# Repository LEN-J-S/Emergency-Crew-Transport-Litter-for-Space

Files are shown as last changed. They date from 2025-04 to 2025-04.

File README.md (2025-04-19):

# Emergency-Crew-Transport-Litter-for-Space
**NASA JSC HACKATHON 2024 - Winner Challenge Category**

Judged by: 
- Robert Howard - NASA
- Tracie Prater - NASA
- Martin Garcia - NASA
- Carson Hula - NASA

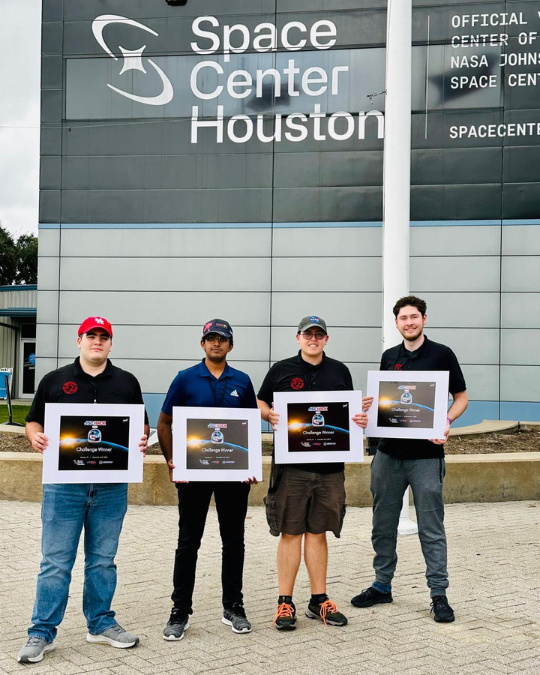
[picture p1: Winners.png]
Winning Photo


***Devpost Link: https://tinyurl.com/p4y2bk32***

## Inspiration

Being part of Robotics-UH and the different CAD challenges we have done in the past, this challenge was a benchmark for involving all engineering majors to brainstorm ideas for this challenge. The CAD assignment was the most exciting part the team was excited to have taken part in bringing different ideas while building the mechanism in CAD.

## What it does

The litter will be used for moving an incapacitated astronauts from their particular location to safety. The whole Litter will be 50lbs and 25lbs will be distributed with each astronauts to be carried at every location. The Litter will also be motor and self propelled. The Litter is also capable of moving for 14 Km at 4Km/hr.

## How we built it

We built the Litter first drawing it on paper and then analyzing all the criteria's are met, we proceeded to work the design on SolidWorks to get the sketch of the final prototype.

## Challenges we ran into

The main challenges we ran into is weight limit criteria of 50lbs for the overall system and locking the astronauts in a rigid position on the Litter. Another challenge we ran into was the design process as we had to go through 7 different design iterations.

## Accomplishments that we're proud of

We are proud that we have learned the different ideas brainstormed for the different iterations of design. We were also proud that different engineering teams brainstormed in each integral part of the design process. We are also proud that the we were able to manage tasks diligently and efficiently.

## What we learned

We learned how to solve different engineering challenges involved in designing the Litter. The different challenges allowed us to through different variations of the challenge to make the design better and meet the criteria of 50 lbs.

## What's next for Lunar Incapacitated Crew Rescue Litter

The next objective of the Litter is to be tested using different simulations in virtual environments and then to be tested in real-life environments. After the successful launches of these, they can be used in an emergency situation when an astronauts life is in danger.

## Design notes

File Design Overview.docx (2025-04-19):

Challenge 2: Emergency Crew Transport

Len Johns Shaji,Tyler Martelon, Aaron Hinkle, Ethan Bush, Celine Cherian

Overview of Design Criteria

Design and modeling of an emergency transportation system for an incapacitated crew member during an EVA. This system should be able to propel itself at a constant speed of 4 km/h and only require directional input from an operator. This system should hold onto an incapacitated astronaut and completely immobilize them during transport. The system should weigh no more than 50 lbs. (under earth gravity conditions) and be able to be broken down into pieces of at most 25 lbs. each for transport, additionally it must support up to 243 lbs. of added mass on the system. The system should take advantage of the construction of the xEMU space suit’s design where possible for the transport and immobilization of a crew member. Under the most ideal situation the system overall will not exceed 25 lbs. total to enable an entire system to be carried by a single individual however this is a highly encouraged design goal and not a design requirement.

Structural Design

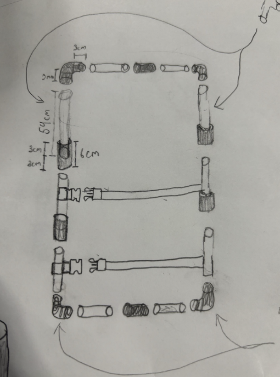
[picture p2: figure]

We based the system on a set of tubes fastened with clip-together fasteners. These tubes and fasteners are intended to be stored bundled together and connected to a crew member’s utility belt or thigh. A steel pin in each pipe section secures the pipes within their fasteners and provides a snug fit that partially retains the pipes due to friction. When fully assembled, this makes a roughly 182x70cm rectangular structure on which to secure a crew member.

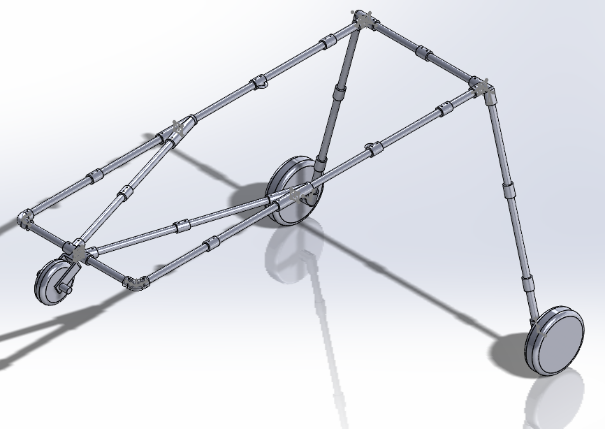
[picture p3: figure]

Securing a crew member to the pipe frame is accomplished by utilizing Beta cloth straps which secure entirely around the PLSS, CHUT, and arms on the upper body, over the knees, and under the thighs and ankles of the crew member. Additionally, there is hardware to mount the hardware pins located on the waist of the xEUV suit to the frame to further secure an individual to the system.

An early design concept for system frame

Once a crew member is secured to the frame the operator of the system can then fold out the two passive support wheels and one hub motor-powered propulsion wheel. Folding the wheels out is assisted by areas to insert the removable handlebar to add leverage and more easily get the system onto its wheels, once folded into the correct position these wheels and the sections of pipe they’re connected to will lock into place with a spring-loaded pin.

CAD model of full frame structure minus straps

Material Selection

As weight and strength are both important factors in this design, the material selection was a quite contentious subject in the design discussion. The biggest need of the design was for a structural material that could:

-Withstand the forces of weight added to the system

-Withstand the lunar environment and its hazards including regolith and solar radiation

-Be lightweight and enable the lightest possible system without sacrificing usability/stability.

With these parameters in mind, we quickly went through multiple options including PEEK plastic, fiberglass, Nomex netting, and others. We narrowed down our search to aluminum and carbon fiber and ended up switching between the two options for some time during the design process, eventually deciding on carbon fiber for the overall structure and aluminum for the fasteners.

Carbon fiber was selected for its excellent strength-to-weight ratio. Being an overall lightweight material with great tensile strength it was a good pick for the overall structure of the frame. While we considered making the fasteners out of carbon fiber as well, we ended up deciding that the forces being exerted on these pieces would probably be too high for it to be practical.

While aluminum was considered for the overall structure it was still too heavy despite its low mass compared to other metals. Rather after opting not to use carbon fiber fasteners a well we decided that using aluminum for the fasteners would be better to handle the forces acting on the fastener pieces.

Other than the structural components the straps were also a major material decision. Given the fact most fabrics aren’t well equipped for the conditions on the moon, we asked advice from some professionals in the space and were suggested to use either beta cloth or nomex fabric. Nomex was a promising prospect but was too heavy and contributed too much to the overall mass for us to consider going forward with. As the only other option was beta cloth and it had acceptable weight we selected it as the strap material.

Electronics integration

To enable the system to best be able to propel itself with the lowest weight possible we had to carefully consider the type of electronics that would be utilized. To maintain a speed of 4 km/h on the lunar surface we found we’d need to use a 70-watt motor running off of 24-volt power. In order to supply this motor with energy we opted to utilize a 13000 mAh lithium polymer battery for its power-to-weight ratio which allows a much greater energy density with less mass added to the system. The motor itself is a fully enclosed dust-proof hub motor integrated into the wheel assembly.

In order to control the motion of the system we’re utilizing wireless communication between two ESP32 microcontrollers and a three-position switch. The system has a simple selection between forward, backward, and stopped for motion as it is all it will need, any type of speed adjustment will add points of failure and mass that are not needed for the system’s function.

Computer-Aided Design work

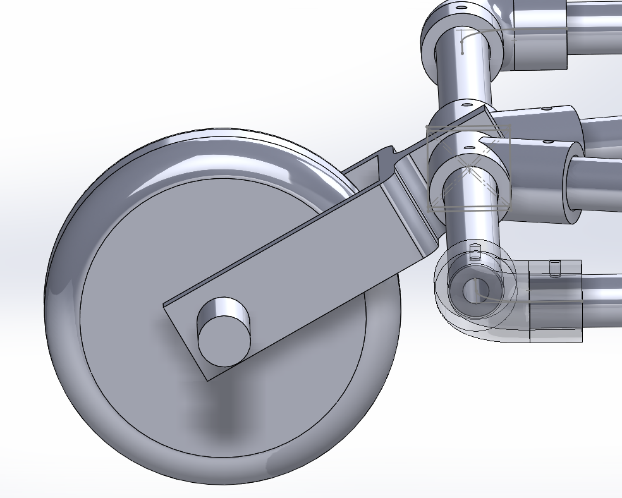
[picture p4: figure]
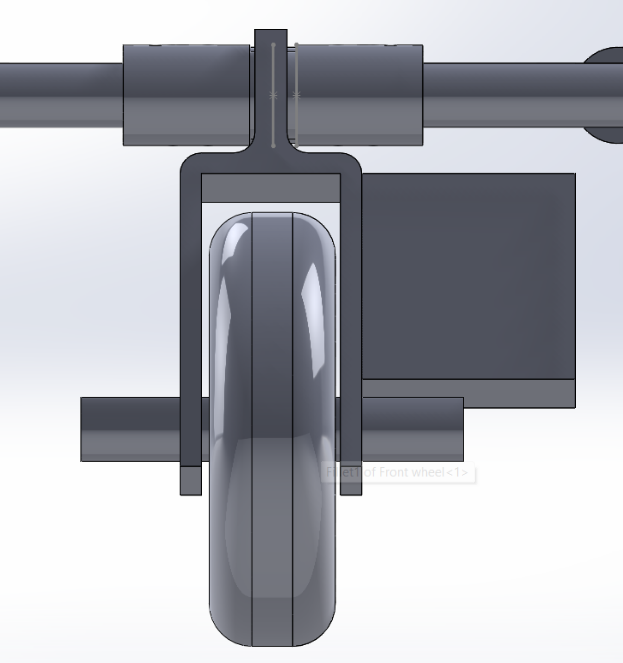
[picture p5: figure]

As part of this project, we made use of SolidWorks, a CAD software popular among mechanical engineering students at our university. We developed models for each part of the structure and combined them into a full assembly model. The following are images of the model produced.

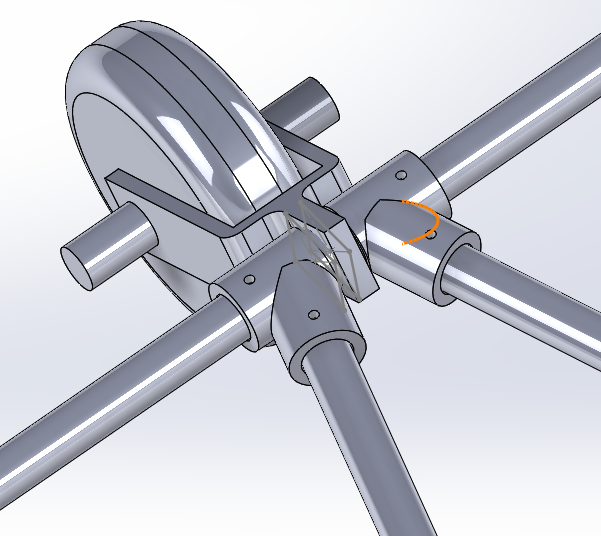
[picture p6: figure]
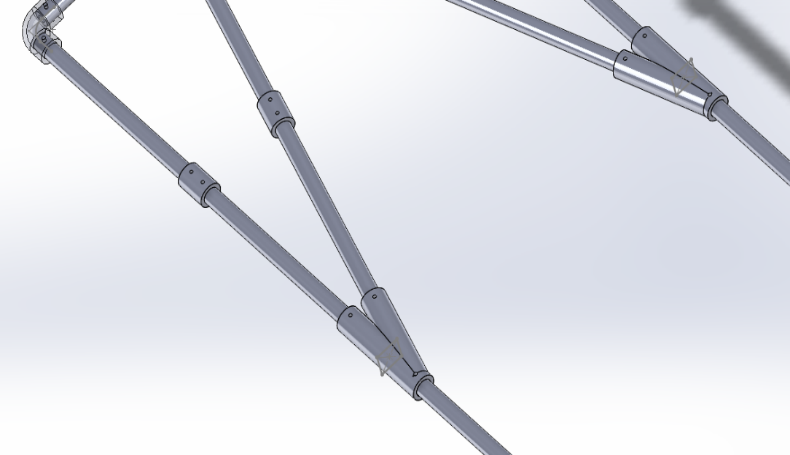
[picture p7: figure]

Cost Analysis

Below is the compiled cost data for all system components.

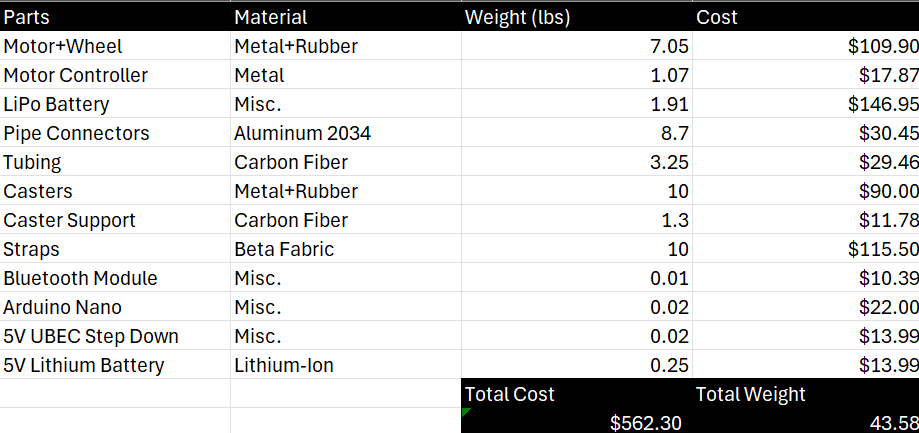
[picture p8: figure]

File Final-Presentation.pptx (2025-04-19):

## Challenge 2: Emergency Crew Transport

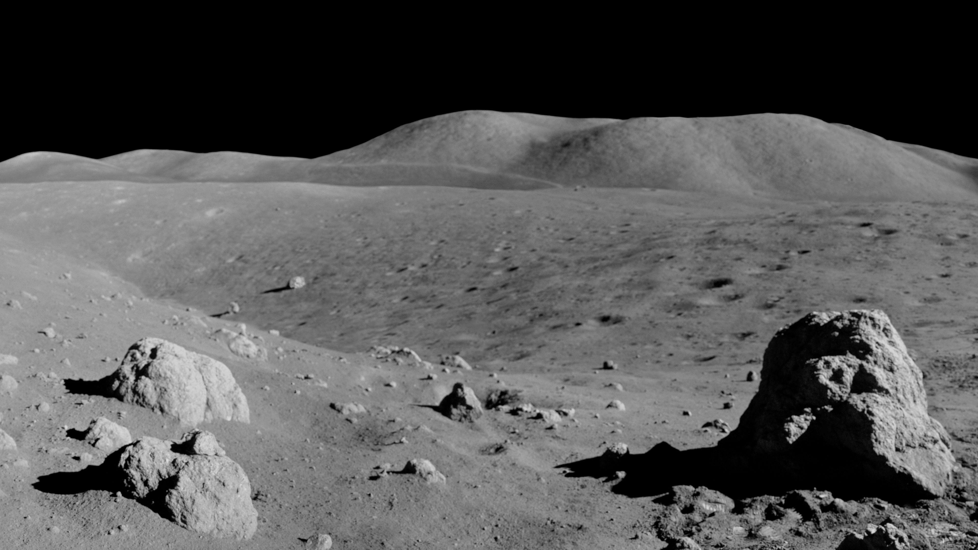
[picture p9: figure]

Len Johns Shaji, Aaron Hinkle, Ethan Bush, Tyler Martelon,
Celine Cherian

## Part 1: Unpressurized transit vehicle

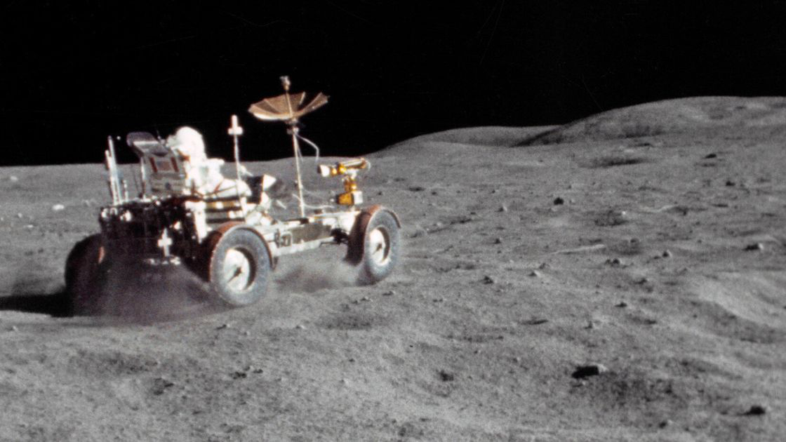
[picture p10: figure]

- Develop a lightweight vehicle to transport an incapacitated crew member wearing an EVA suit.
- Ensure materials selected can withstand lunar conditions
- Design a structure that can withstand up to 5 times its weight

## Material Selection

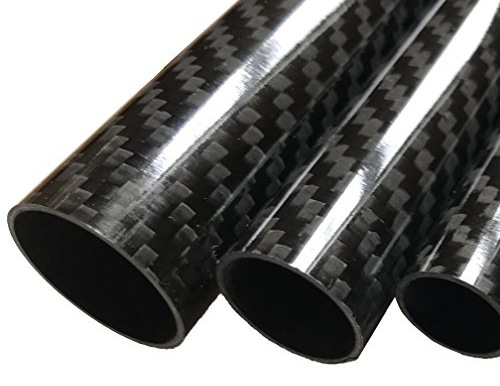
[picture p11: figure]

- Structural - Aluminum; A comfortable balance of weight and strength.
- Transport Harness – Nomex fabric; Environmental resistance and high strength.
- Electronics Protection – Epoxyseal; Protects electronics from dust exposure.
- Tires – Vulcanized Rubber; Combined with airless geometry rubber should function over the short distances intended for the system.
- Other smaller component materials vary.

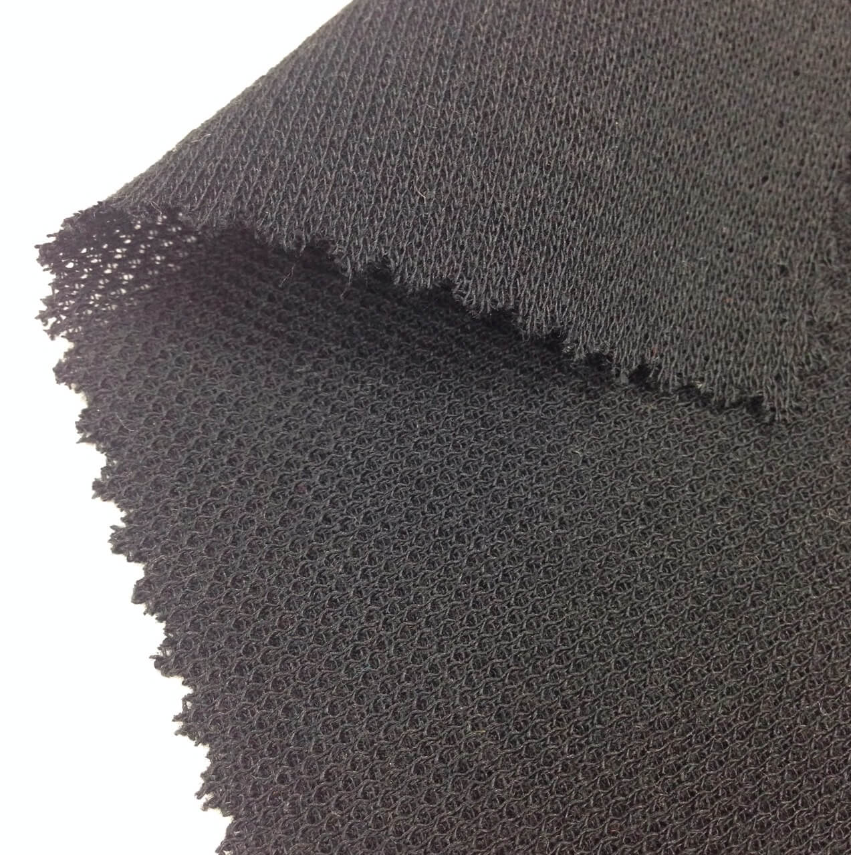
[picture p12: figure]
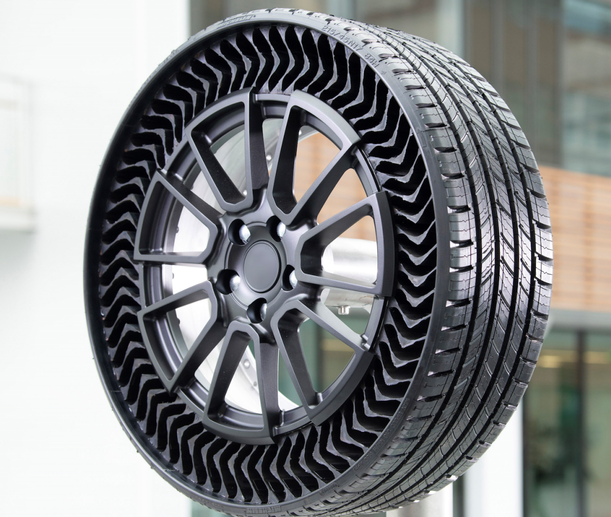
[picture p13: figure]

## Structural Design

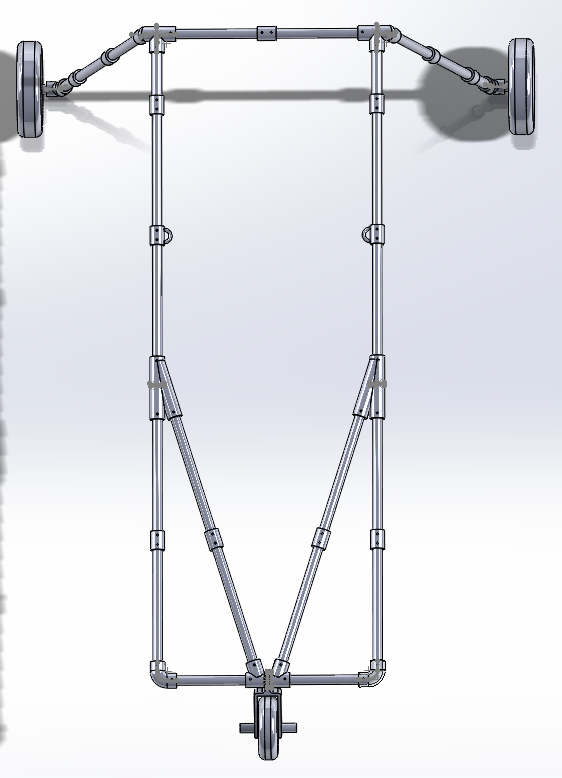
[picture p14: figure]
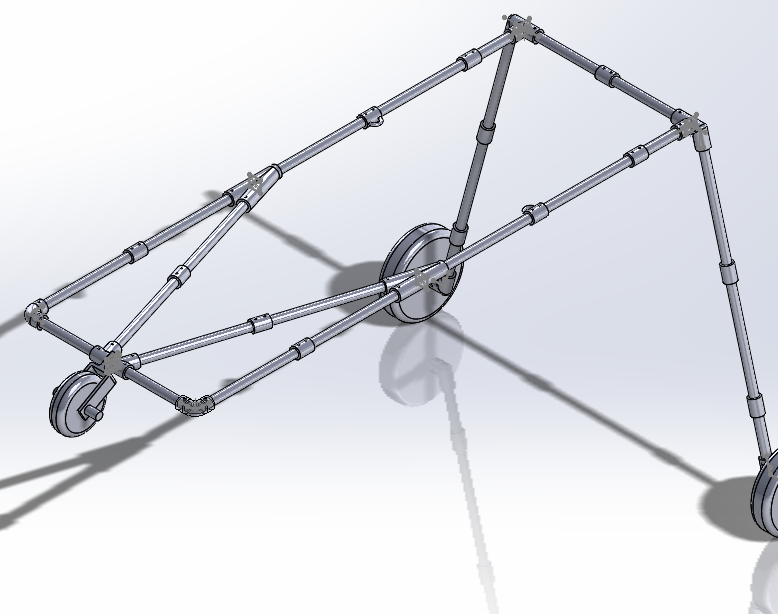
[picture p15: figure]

- Collapsable structure, folded to be carried on astronaut’s thigh.
- Spring-loaded locking mechanism
- Easy assembly

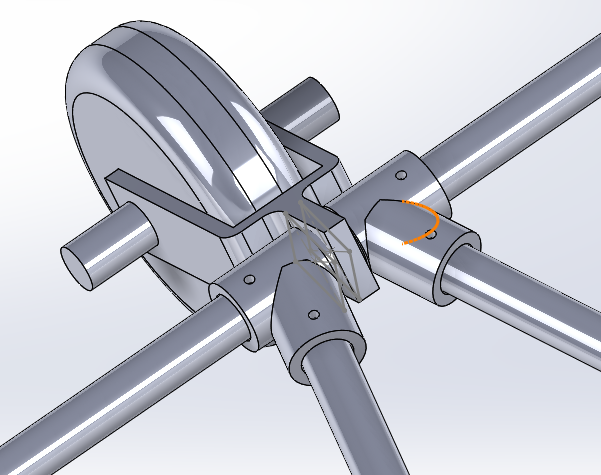
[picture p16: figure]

## Electronics Integration

- Drive motor in the 50-100 watt power range.
- 13000 mAh LiPo battery; Provides high energy density with low mass.
- ESP32-based wireless drive control.

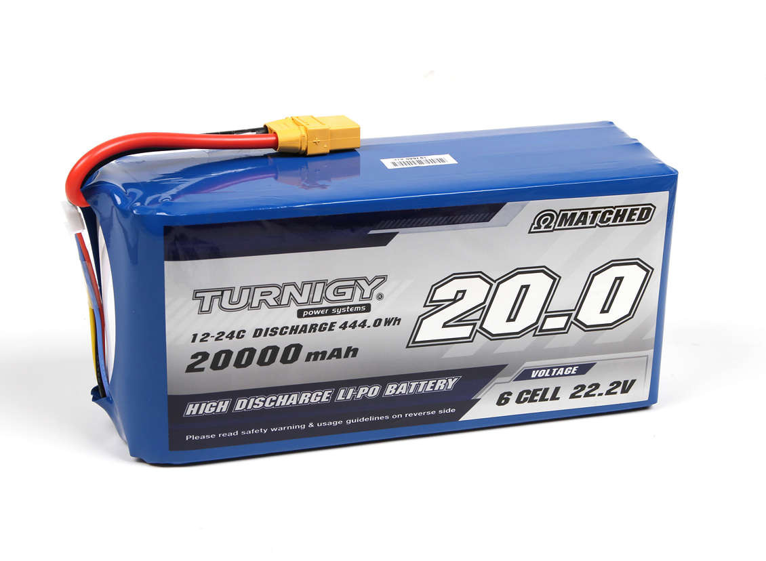
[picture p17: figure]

## Cost Analysis

Parts | Material | Weight (lbs) | Cost
Motor+Wheel | Metal+Rubber | 7.05 | $109.90
Motor Controller | Metal | 1.07 | $17.87
LiPo Battery | Misc. | 1.91 | $146.95
Pipe Connectors | Aluminum 2034 | 8.7 | $30.45
Tubing | Carbon Fiber | 3.25 | $29.46
Casters | Metal+Rubber | 10 | $90.00
Caster Support | Carbon Fiber | 1.3 | $11.78
Straps | Beta Fabric | 10 | $115.50
Bluetooth Module | Misc. | 0.01 | $10.39
Arduino Nano | Misc. | 0.02 | $22.00
5V UBEC Step Down | Misc. | 0.02 | $13.99
5V Lithium Battery | Lithium-Ion | 0.25 | $13.99
Total Cost: $562.30 | Total Weight: 43.58 lbs

## Risk Analysis

- Carbon Fiber structure shattering
- Unexpected power depletion
- Fastener failure
- Carbon Fiber decay causing structural failure
- Insufficient motor power for terrain

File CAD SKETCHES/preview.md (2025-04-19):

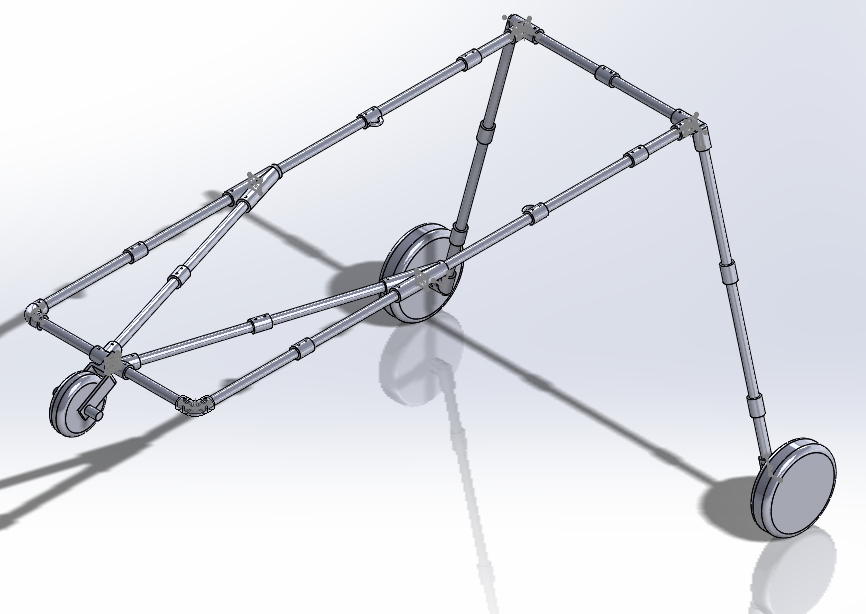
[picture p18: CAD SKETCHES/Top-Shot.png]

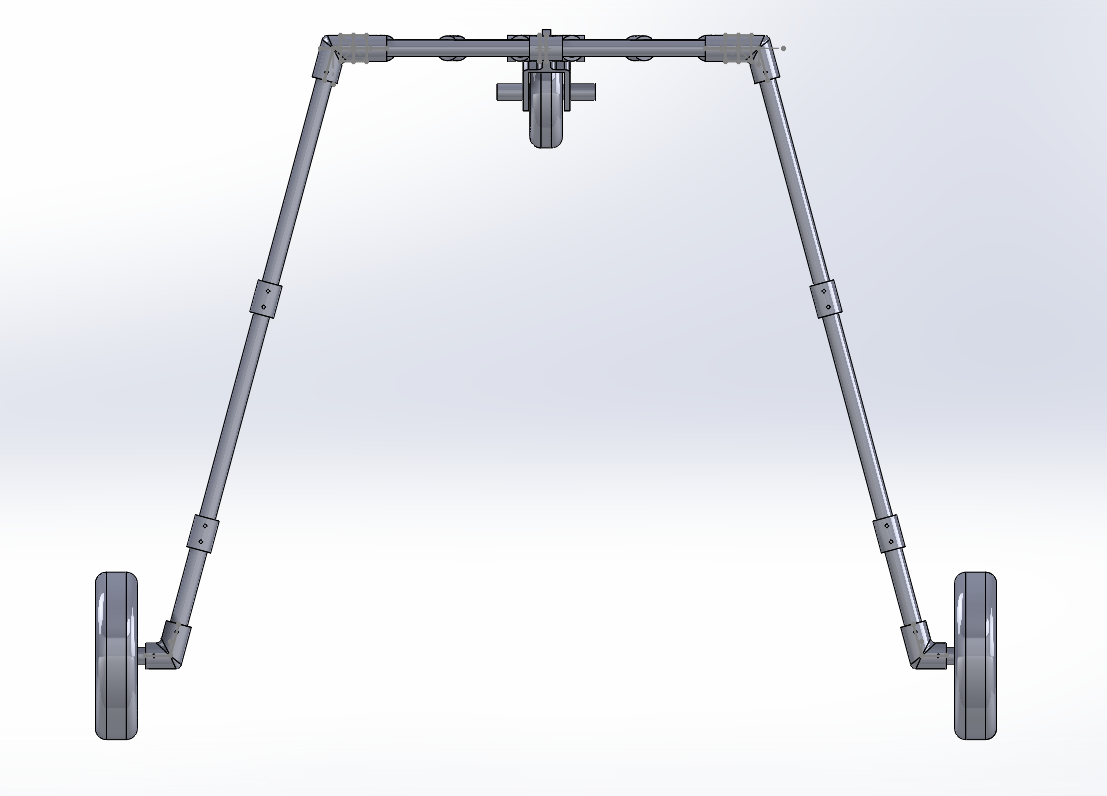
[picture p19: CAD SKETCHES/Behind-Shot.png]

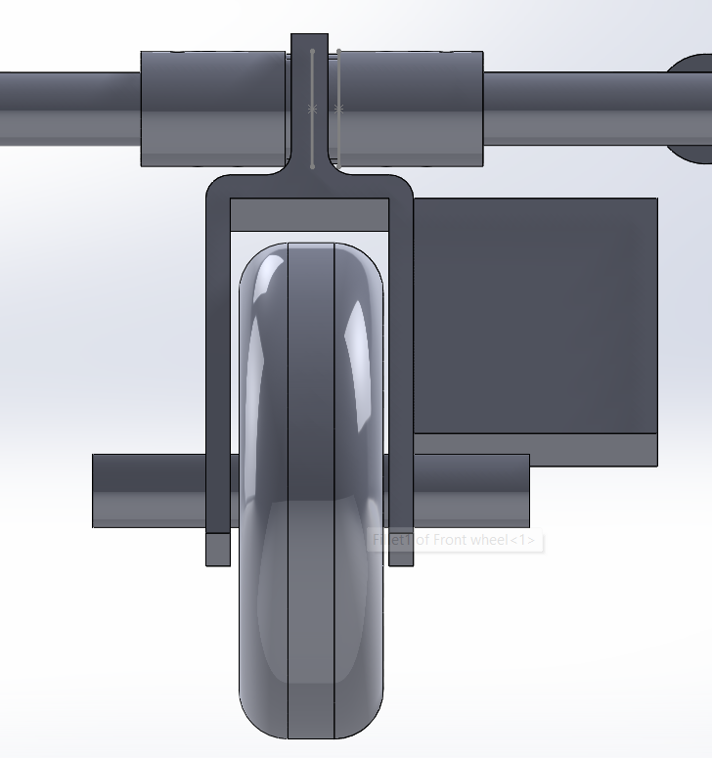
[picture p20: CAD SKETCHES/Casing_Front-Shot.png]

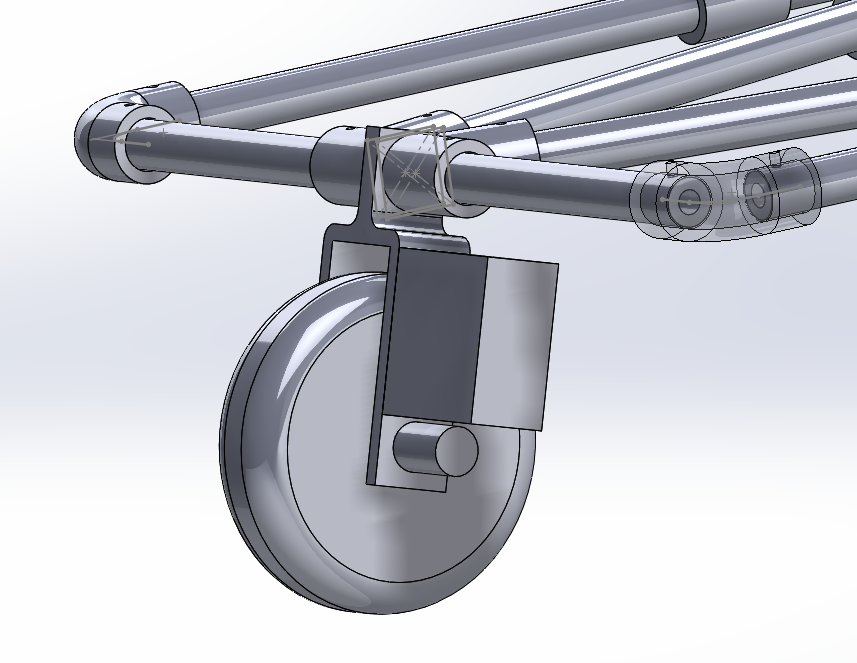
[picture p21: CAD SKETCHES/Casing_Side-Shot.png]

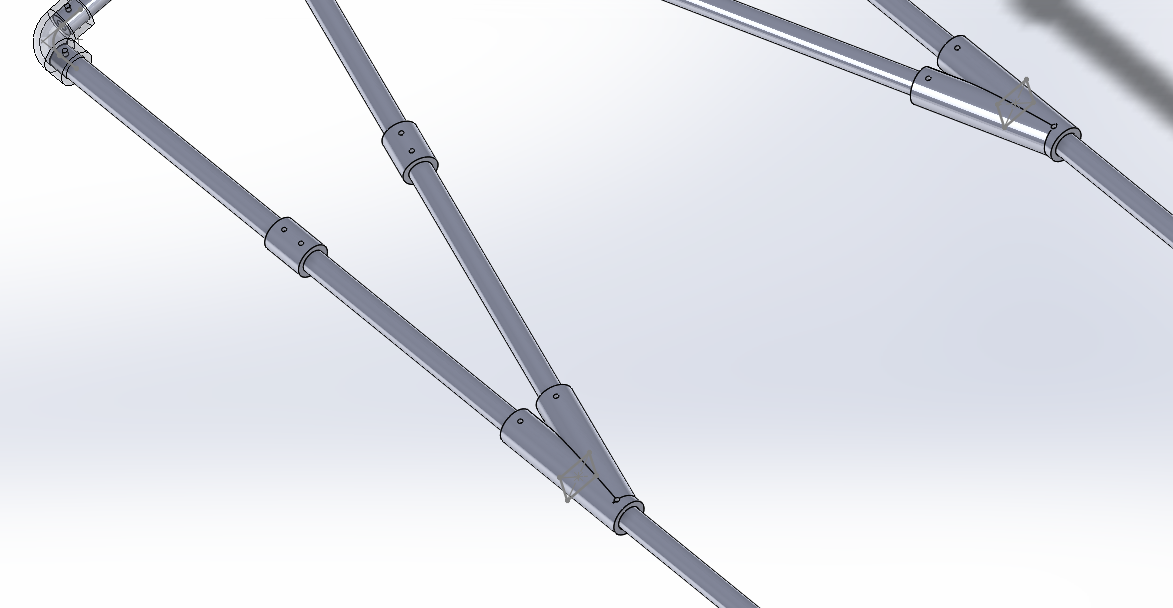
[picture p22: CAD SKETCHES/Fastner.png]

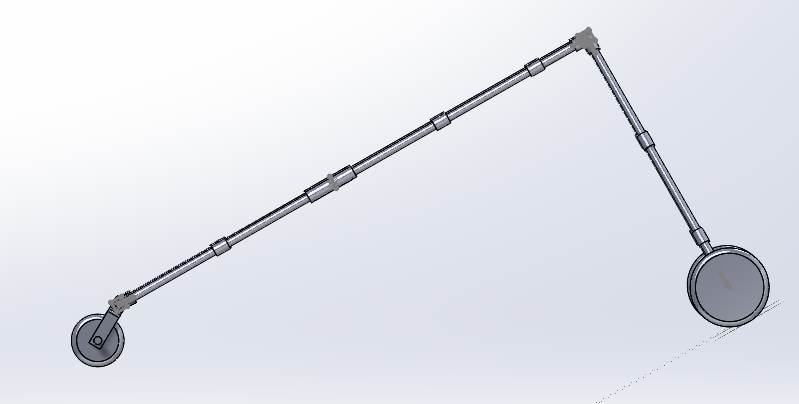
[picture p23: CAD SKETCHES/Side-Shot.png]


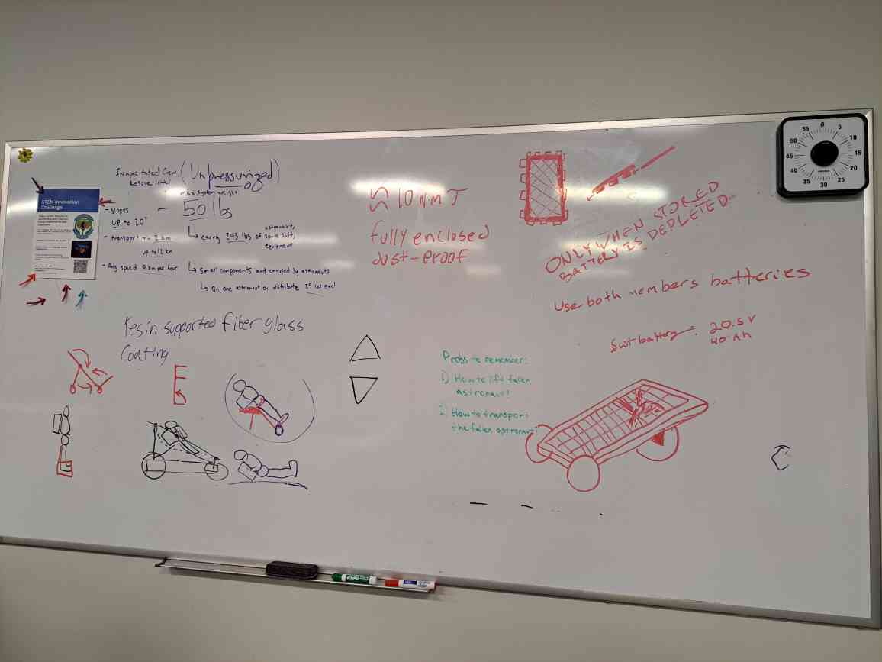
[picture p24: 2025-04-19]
HAND SKETCHES/B3.jpg

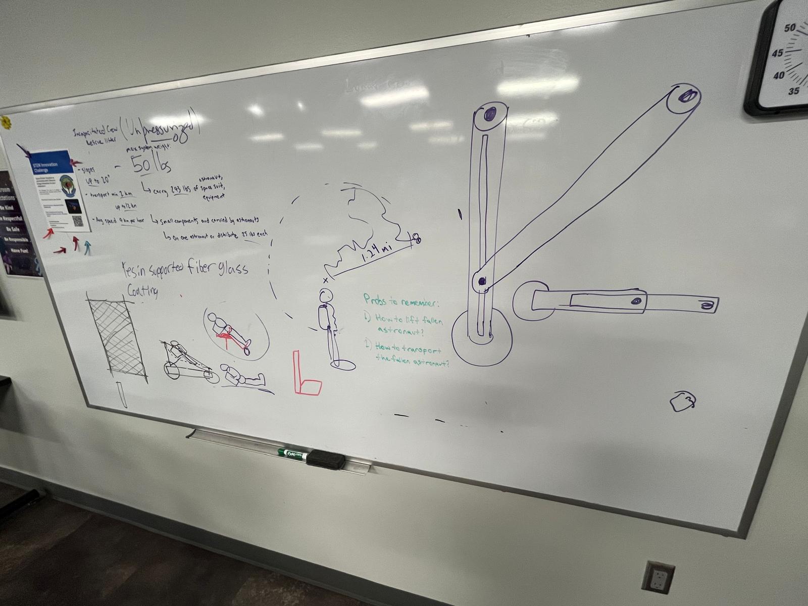
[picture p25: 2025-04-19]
HAND SKETCHES/B2.jpg

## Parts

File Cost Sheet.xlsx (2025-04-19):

Parts | Material | Weight (lbs) | Cost | Total Cost
Motor+Wheel | Metal+Rubber | 7.05 | $109.90 | $562.30
Motor Controller | Metal | 1.07 | $17.87
LiPo Battery | Misc. | 1.91 | $146.95
Pipe Connectors | Aluminum 2034 | 8.7 | $30.45 | Total Weight (lbs)
Tubing (Fabrication) | Carbon Fiber | 3.25 | $29.46 | 43.58
Casters | Metal+Rubber | 10 | $90.00
Caster Support (Fabrication) | Carbon Fiber | 1.3 | $11.78
Straps (Fabrication) | Beta Fabric | 10 | $115.50 | LIMIT: 50 lbs
Bluetooth Module | Misc. | 0.01 | $10.39 | Excess Weight: 6.42 lbs
Arduino Nano | Misc. | 0.02 | $22.00
5V UBEC Step Down | Misc. | 0.02 | $13.99
5V Lithium Battery | Lithium-Ion | 0.25 | $13.99

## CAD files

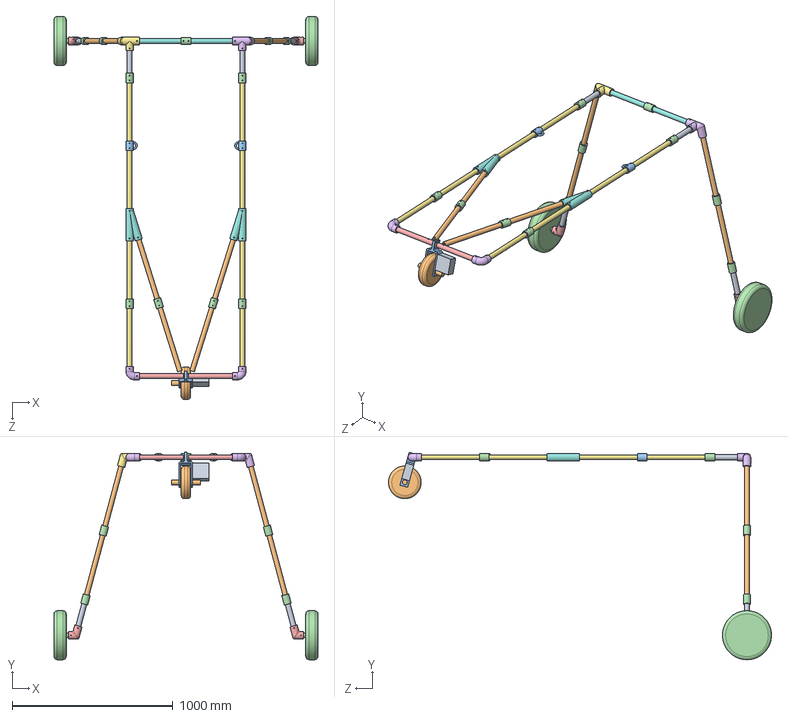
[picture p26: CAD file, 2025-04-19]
CAD FILES/JSC HACK.SLDASM
1640.1 x 1289.2 x 2379.5 mm
17.4 degree connector wall x 2
42mm Side bars x 8
corner pipe x 2
35mm bars x 2
Straight pipe x 11
Straight pipe with ring x 2
Leg support bar x 8
20cm pipe x 4
Top Pipe x 2
corner T pipe
corner T pipe Inverse
Pole to tire x 2
back wheels x 2
Wheel hub
Front wheel
casing

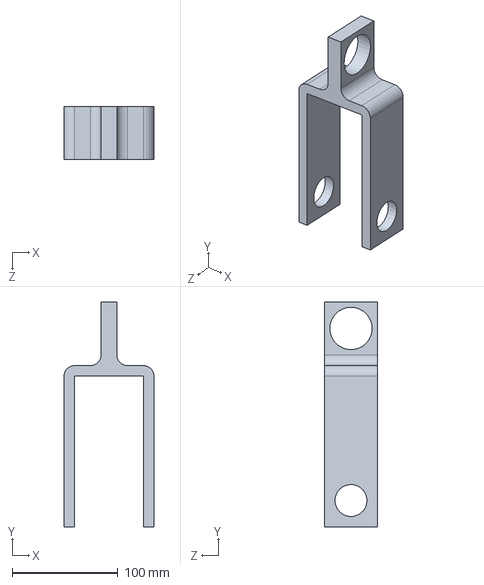
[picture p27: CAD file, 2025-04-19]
CAD FILES/Wheel hub.SLDPRT
85.0 x 212.4 x 50.0 mm

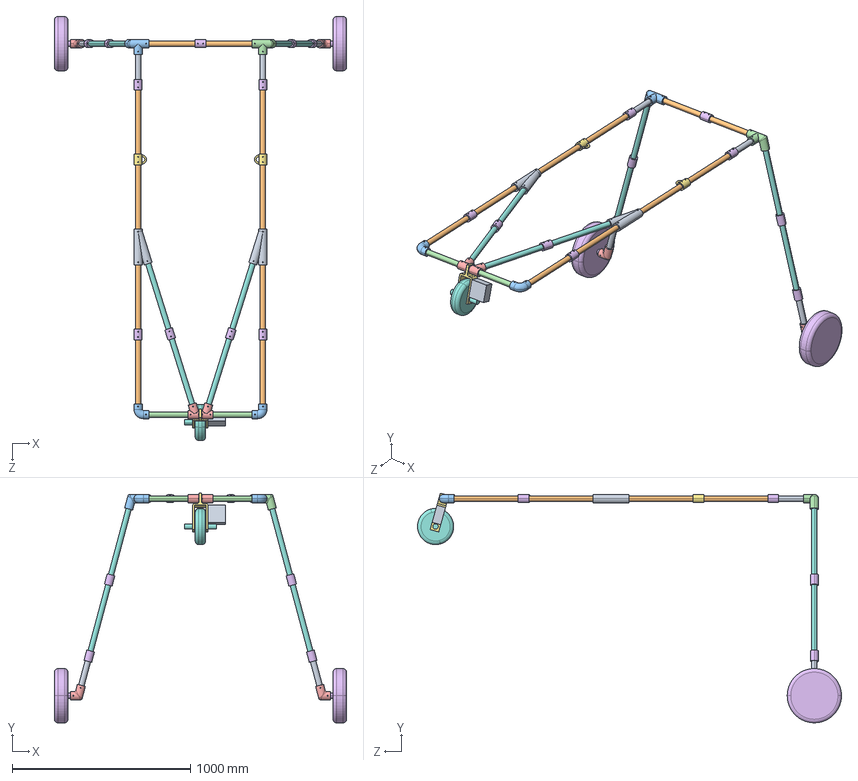
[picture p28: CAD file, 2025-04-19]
CAD_DESIGN.STEP
1640.1 x 1289.2 x 2379.5 mm
17.4 degree connector wall x 2
42mm Side bars x 8
corner pipe x 2
35mm bars x 2
Front wheel pivot connector
Straight pipe x 11
Straight pipe with ring x 2
Leg support bar x 8
20cm pipe x 4
Top Pipe x 2
corner T pipe
corner T pipe Inverse
Pole to tire x 2
back wheels x 2
Wheel hub
Front wheel
casing

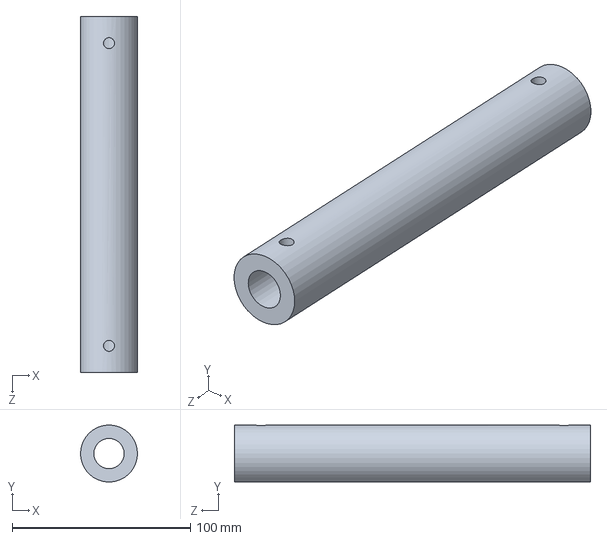
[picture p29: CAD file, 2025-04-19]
CAD FILES/20cm pipe.SLDPRT
32.0 x 31.9 x 200.0 mm

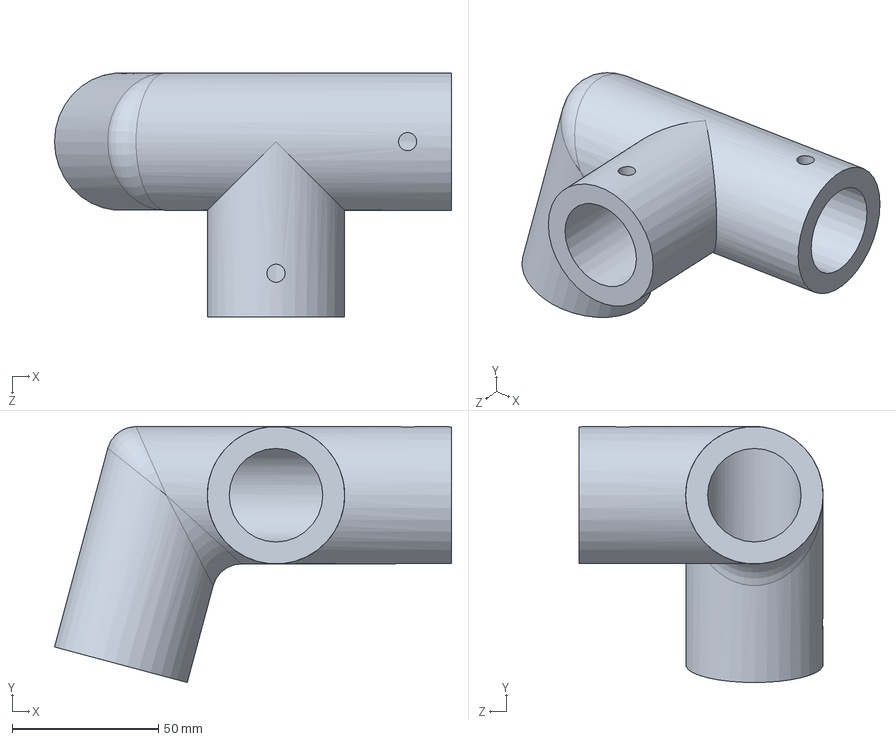
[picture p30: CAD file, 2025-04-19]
CAD FILES/corner T pipe.SLDPRT
135.7 x 87.5 x 83.5 mm

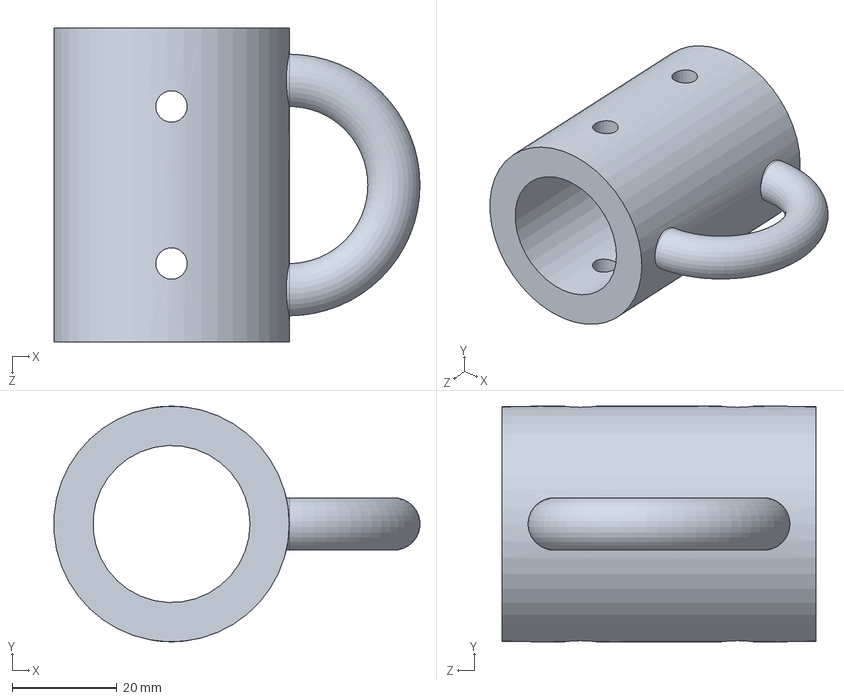
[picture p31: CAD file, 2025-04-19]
CAD FILES/Straight pipe with ring.SLDPRT
69.9 x 45.0 x 60.0 mm

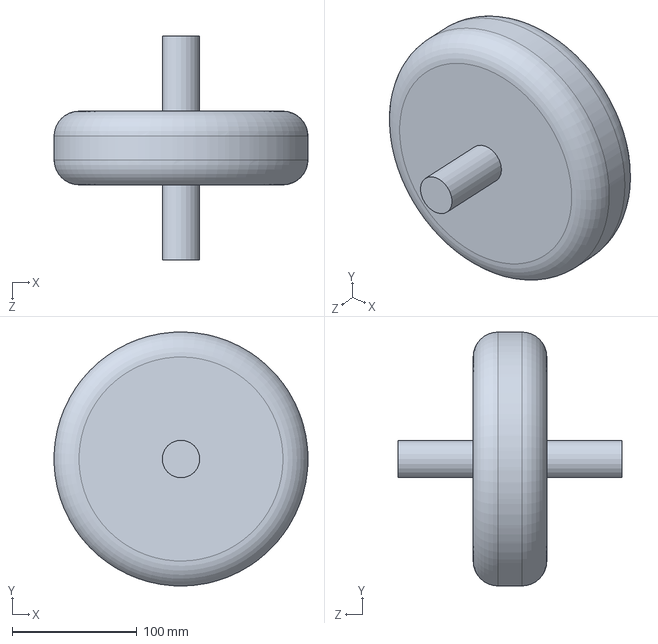
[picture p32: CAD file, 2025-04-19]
CAD FILES/Front wheel.SLDPRT
203.2 x 203.1 x 179.0 mm

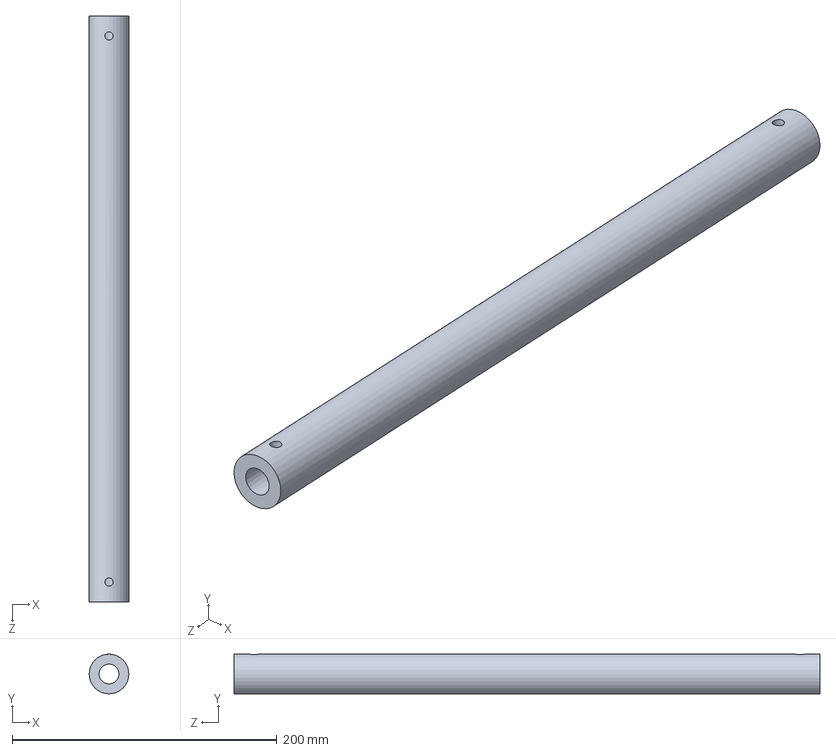
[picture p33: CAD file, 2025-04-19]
CAD FILES/Leg support bar.SLDPRT
30.0 x 30.0 x 442.5 mm

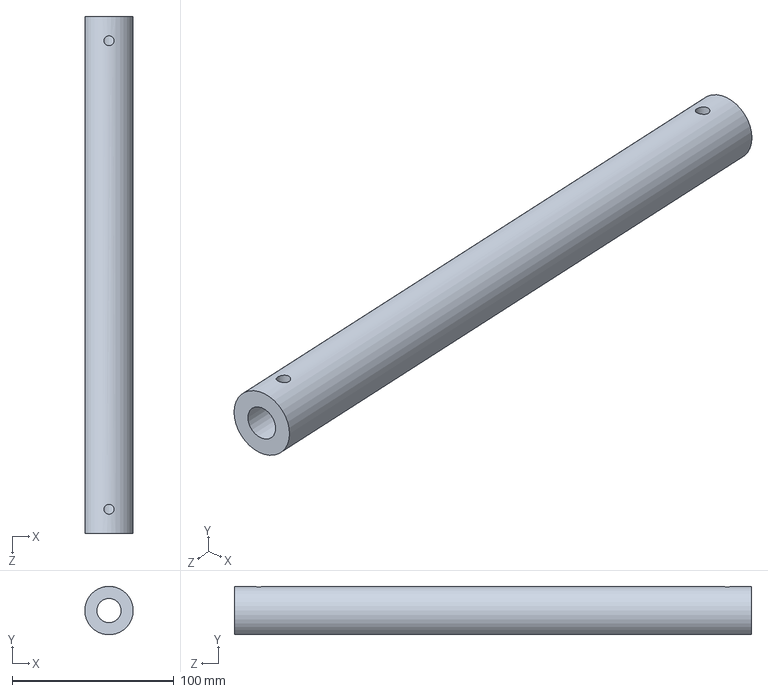
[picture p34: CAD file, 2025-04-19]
CAD FILES/Top Pipe.SLDPRT
30.0 x 29.9 x 320.0 mm

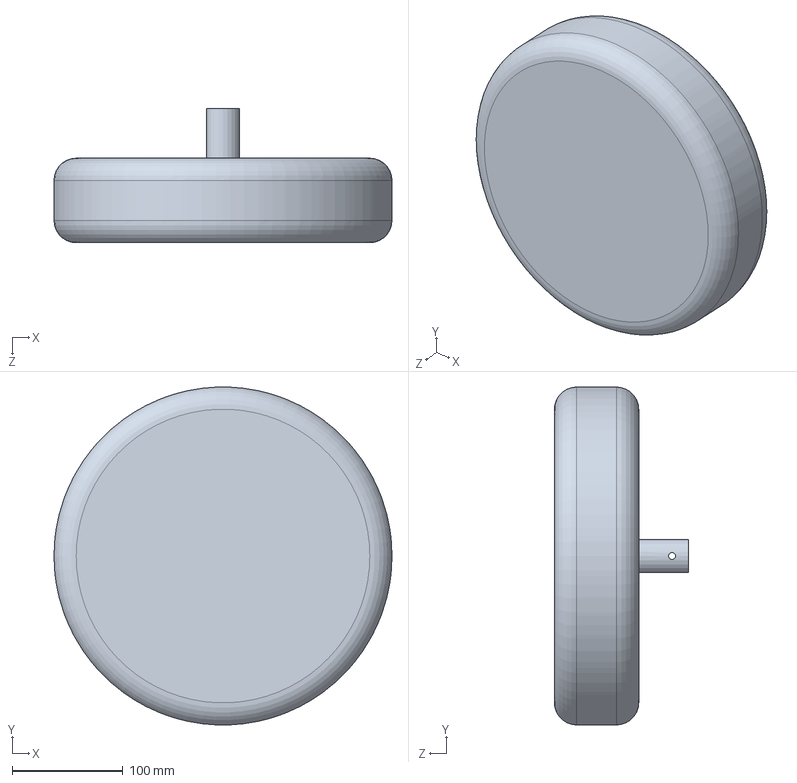
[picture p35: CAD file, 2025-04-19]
CAD FILES/back wheels.SLDPRT
304.8 x 304.8 x 121.2 mm

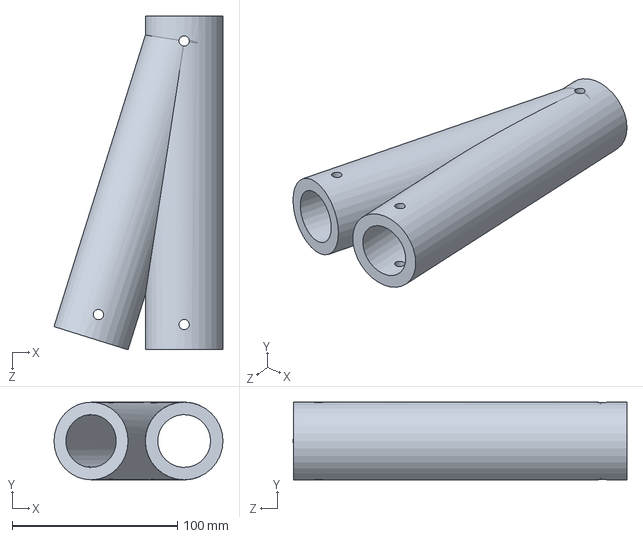
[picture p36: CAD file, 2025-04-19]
CAD FILES/17.4 degree connector wall.SLDPRT
102.3 x 47.0 x 202.0 mm

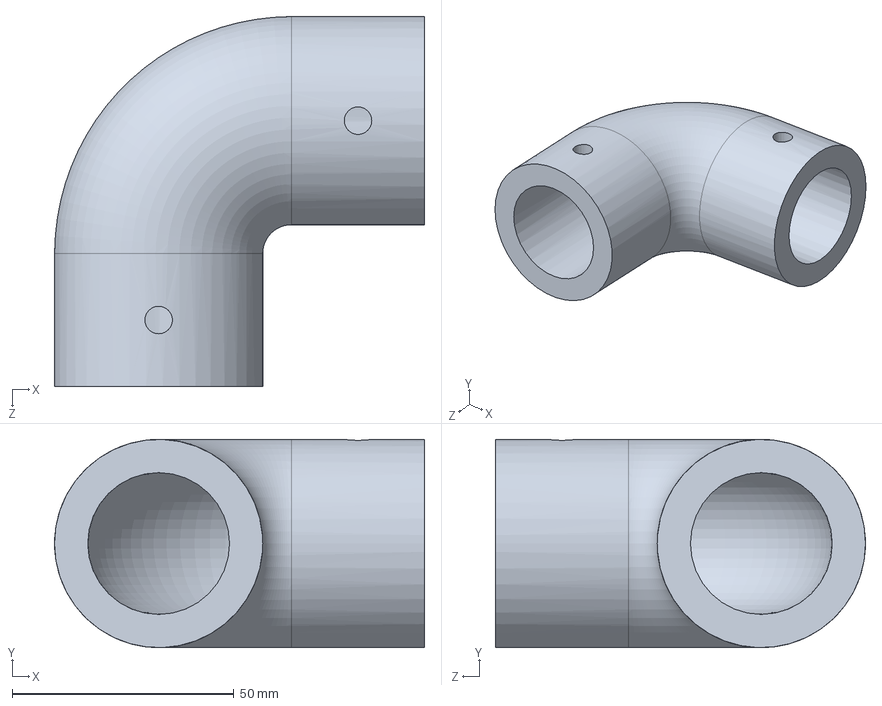
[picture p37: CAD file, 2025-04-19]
CAD FILES/corner pipe.SLDPRT
83.5 x 47.0 x 83.5 mm

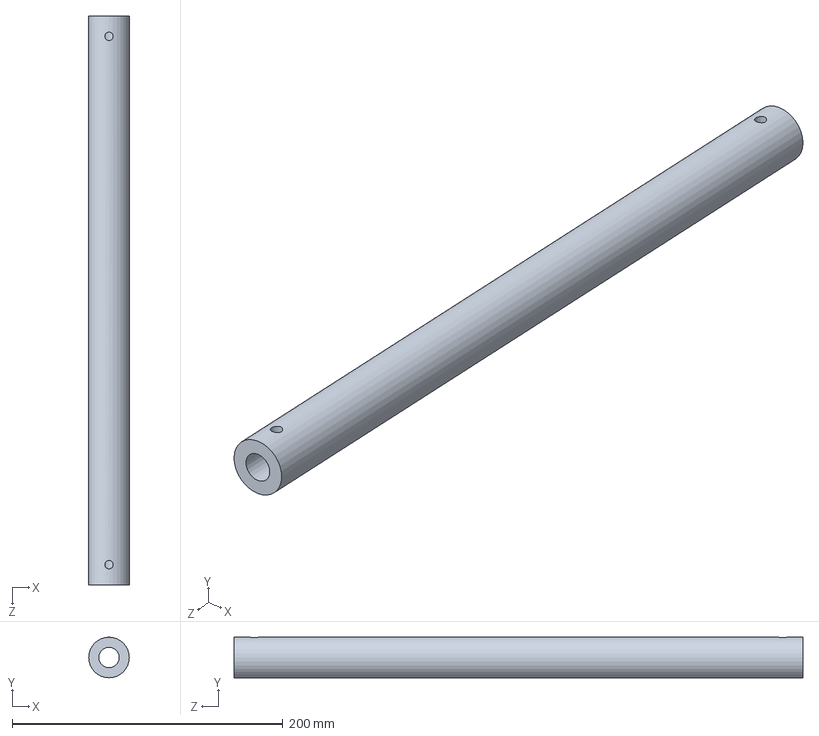
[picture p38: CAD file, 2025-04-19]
CAD FILES/42mm Side bars.SLDPRT
30.0 x 30.0 x 420.0 mm

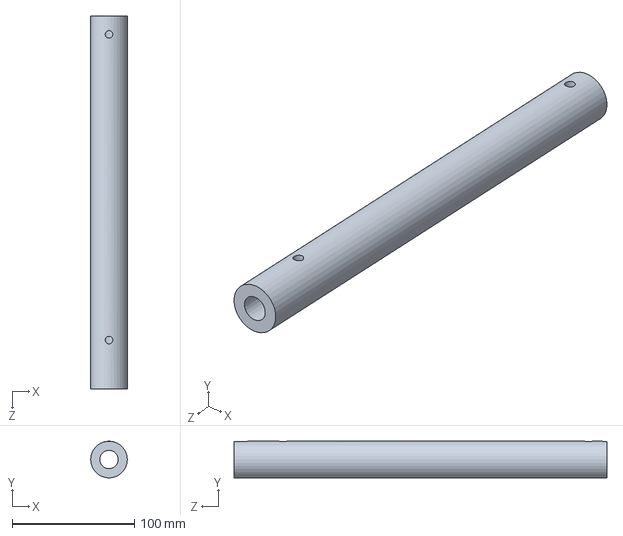
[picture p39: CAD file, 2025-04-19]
CAD FILES/35mm bars.SLDPRT
30.0 x 29.9 x 305.0 mm

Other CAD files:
CAD FILES/corner T pipe Inverse.SLDPRT
CAD FILES/casing.SLDPRT
CAD FILES/Straight pipe.SLDPRT
CAD FILES/Pole to tire.SLDPRT
CAD FILES/Front wheel pivot connector.SLDPRT
